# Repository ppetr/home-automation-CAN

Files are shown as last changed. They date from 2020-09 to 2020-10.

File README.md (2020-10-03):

# Home automation communication network

_*Disclaimer:* This is not an officially supported Google product._

This project aims to create both SW and HW for an inexpensive home automation
communication network based on the
[CAN bus](https://en.wikipedia.org/wiki/CAN_bus) using common components and
infrastructure.

Eventually it will contain hardware plans
([KiCAD](https://en.wikipedia.org/wiki/KiCad)) and software to control
individual modules.

At the moment subdirectories contain work in progress, untested, and not
suitable for any use whatsoever.

## Design goals:

* Local with respect to network changes. That is, changing one part of the
  network should not require modification of the network as a whole.
* Easy to use. Adding or removing devices should be simple.
* Allow complex topologies, ideally multi-star.
* Use existing infrastructure - CAT 5 cables and RJ45 connectors.
* Universal - modules should be able to provide GPIO pins, as well as standard
  short-range communication buses such as I²C.
* Inexpensive.

See also
[Linearizing multi-star network for home automation](https://electronics.stackexchange.com/questions/512147/linearizing-multi-star-network-for-home-automation)
on StackExchange.

## Detailed design

### RJ45 connector for CAN

The project uses the standard [RJ45](https://en.wikipedia.org/wiki/RJ45)
connector and [CAT5](https://en.wikipedia.org/wiki/Category_5_cable) (or better
cables).

For power distribution it uses pins 4 and 5 for positive voltage and pins 7 and
8 for negative (ground) voltage. This is compatible with [Power over
Ethernet](https://en.wikipedia.org/wiki/Power_over_Ethernet). It should be
possible to use any _passive_ PoE injector up to 48V.

Pin pairs 1 & 2 and 3 & 6 are used for the CAN bus. The standard requires that
the CAN bus data connections form a serial bus. In order to support arbitrary
tree [topologies](https://en.wikipedia.org/wiki/Network_topology), each node in
the network provides a linar segment of a CAN bus. This linear segment goes
from pins 1 (_LEFT CAN+_) and 2 (_LEFT CAN-_) to pins 3 (_RIGHT CAN+_) and 6
(_RIGHT CAN-_). All these segments are then concatenated into a single serial
line.

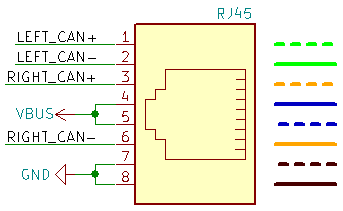
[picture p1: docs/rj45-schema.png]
RJ54 interface


A simple **end node** must connects pins 1-3 and 2-6 to connect the bus segment
"on its left" with the other segment "on its right". At the same time, it
connects its CAN transceiver to these pins and to the ground pins. It can also
draw power from the PoE positive voltage pins.

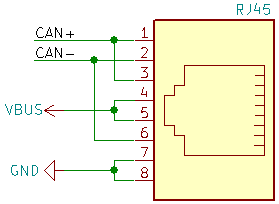
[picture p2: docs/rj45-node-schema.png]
RJ54 end node


A **splitter node** just connects the power pins among all RJ45 connectors. The
data pin connections are more complicated: The CAN network "going from the
left" is first connected to one branch (CAN1), the "right" part of the branch
is connected to the "left" part of the other branch (CAN2), and finally
continues "to the right" (CAN3).

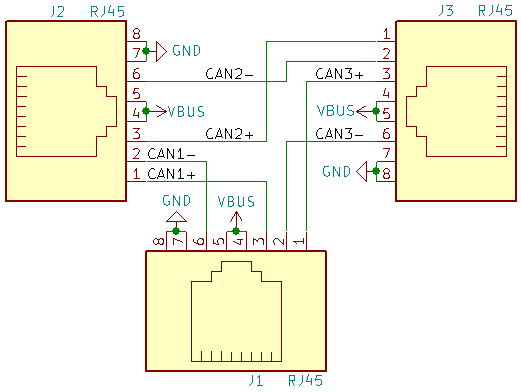
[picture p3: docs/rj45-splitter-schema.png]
RJ54 splitter node


This corresponds to depth-first
[tree traversal](https://en.wikipedia.org/wiki/Tree_traversal) of the network.

Notice that the splitter node is fully symmetric. Therefore any connector can
be used as the one connected to the main network, and all the others as
branches. It can also split into more than two branches. However, in any case
**all branches must be connected** to nodes, even just to dummy ones that only
connect pins 1-3 and 2-6, in order to ensure that the whole network is
interconnected.

Finally, exactly one node on the network must be a **terminating node**, to
provide proper
[electrical termination](https://en.wikipedia.org/wiki/Electrical_termination).
Without such a node the whole network would form a ring and suffer from echoes
(see also [Signal reflection](https://en.wikipedia.org/wiki/Signal_reflection)).

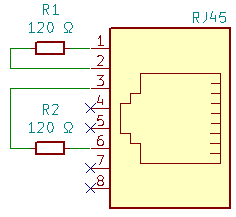
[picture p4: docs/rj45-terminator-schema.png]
RJ54 terminator node


## Contributions and future plans

Once a skeleton of the project becomes available, contributions will be
welcomed! Please see [Code of Conduct](docs/code-of-conduct.md) and
[Contributing](docs/contributing.md).

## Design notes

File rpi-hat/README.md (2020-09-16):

# Universal Raspberry Pi CAN Hat board

Provides CAN interface using the standard
[D-sub](https://en.wikipedia.org/wiki/D-subminiature) DE-9 connector and our
custom RJ-45 connector.

The board should comply to the requirements stated in
https://github.com/raspberrypi/hats. If you encounter any violation or
deviation, please open an issue.

The schema is loosely based on
https://www.disk91.com/2015/technology/hardware/design-a-raspberry-pi-hat-shield/

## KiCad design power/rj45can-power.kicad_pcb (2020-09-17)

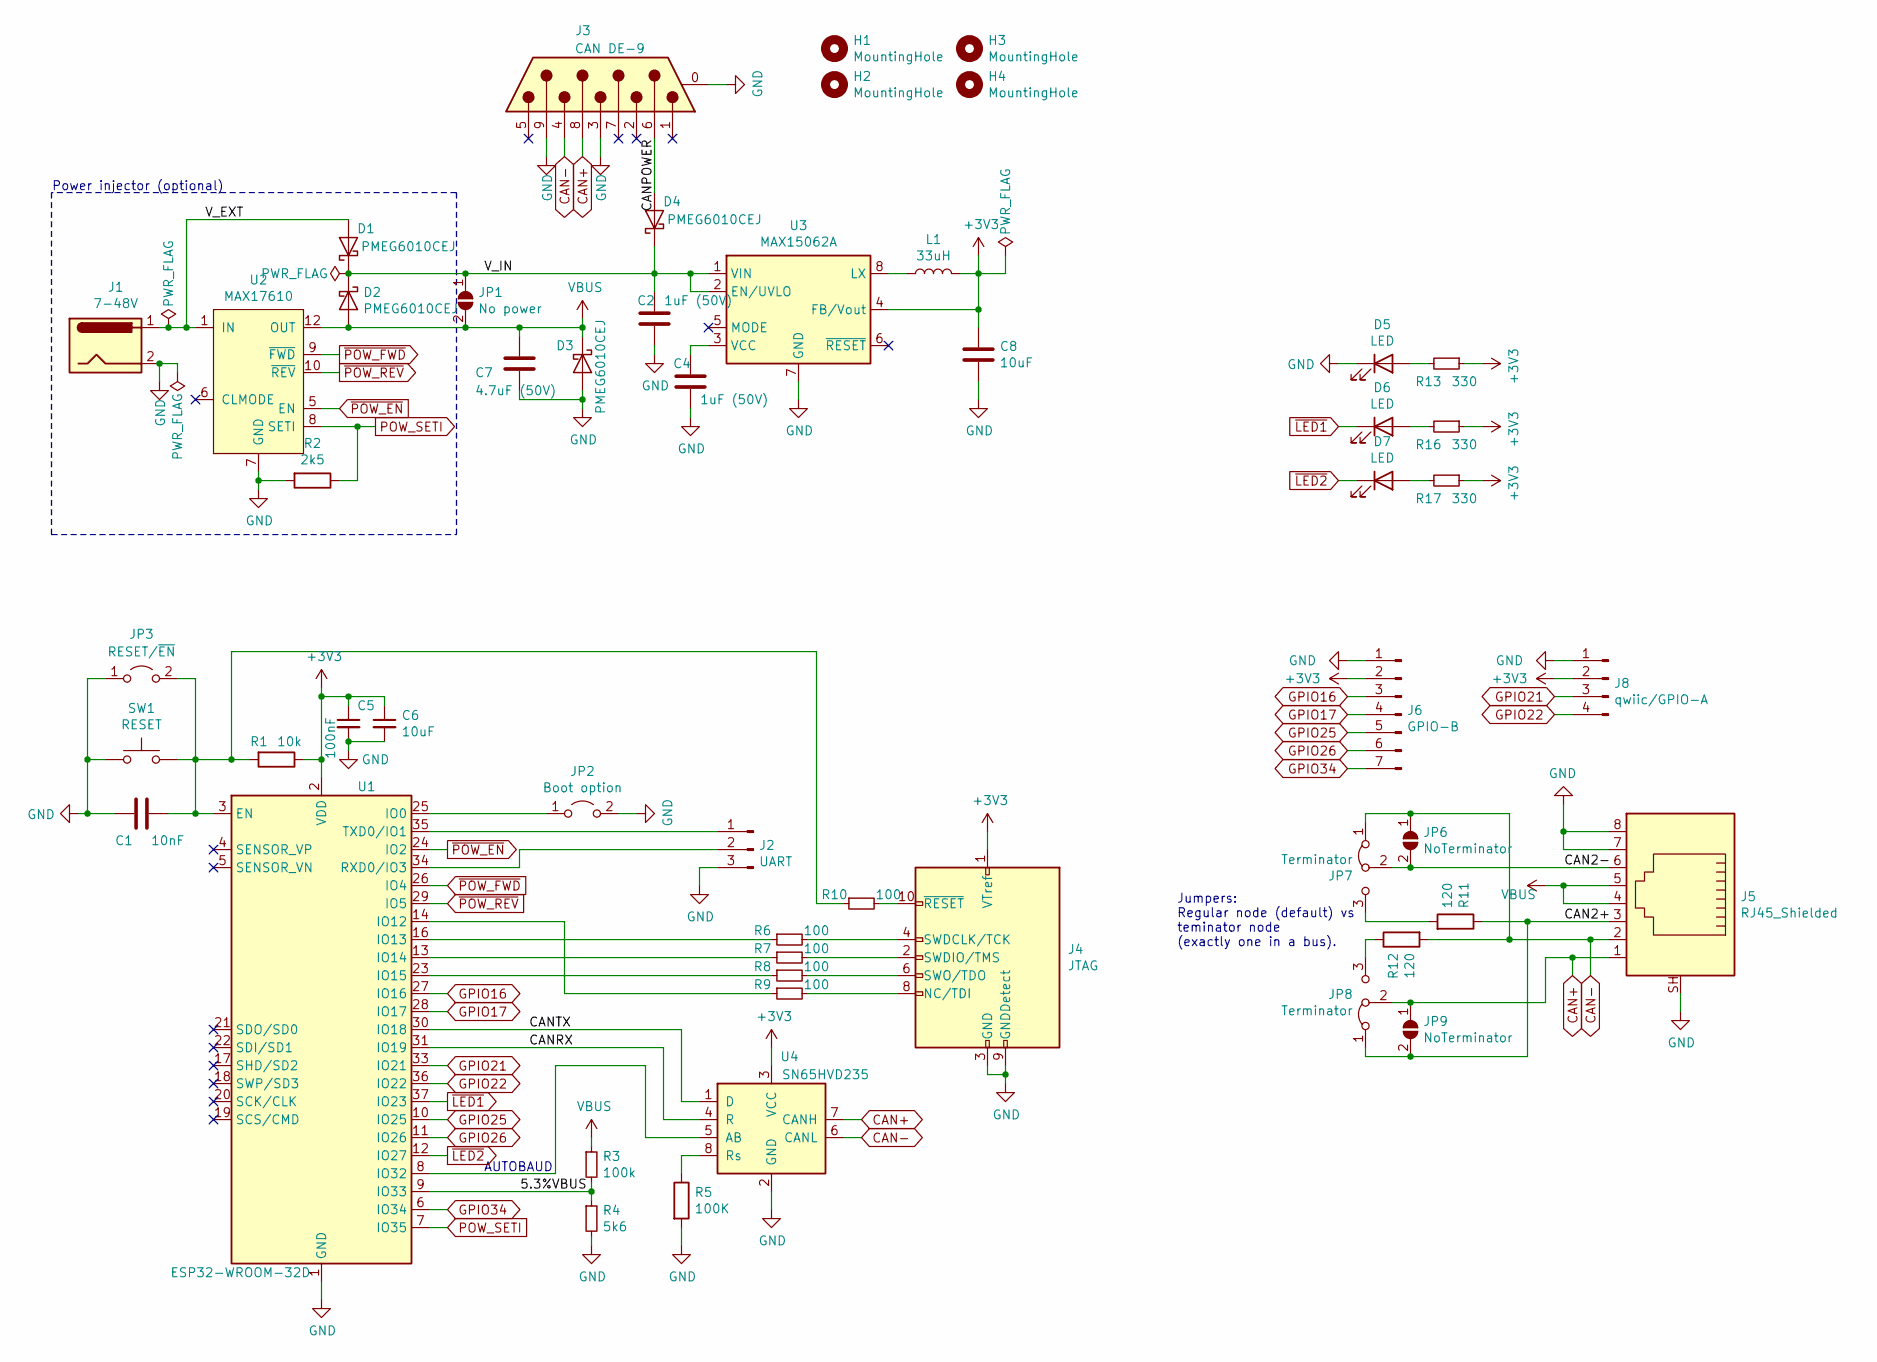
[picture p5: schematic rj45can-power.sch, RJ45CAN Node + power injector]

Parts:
C1: 10nF; C_0603_1608Metric_Pad1.05x0.95mm_HandSolder
C2, C4: 1uF (50V); C_0603_1608Metric_Pad1.05x0.95mm_HandSolder
C5: 100nF; C_0603_1608Metric_Pad1.05x0.95mm_HandSolder
C6, C8: 10uF; C_0603_1608Metric_Pad1.05x0.95mm_HandSolder
C7: 4.7uF (50V); C_0603_1608Metric_Pad1.05x0.95mm_HandSolder
D1, D2, D3, D4: PMEG6010CEJ; D_SOD-323F
D5, D6, D7: LED; LED_0603_1608Metric_Pad1.05x0.95mm_HandSolder
H1, H2, H3, H4: MountingHole; MountingHole_2.2mm_M2
J1: 7-48V; BarrelJack_Horizontal
J2: UART; JST_SH_BM03B-SRSS-TB_1x03-1MP_P1.00mm_Vertical
J3: CAN DE-9; DSUB-9_Male_Horizontal_P2.77x2.84mm_EdgePinOffset4.94mm_Hou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
J4: JTAG; IDC-Header_2x05_P2.54mm_Vertical
J5: RJ45_Shielded; RJ45_Ninigi_GE
J6: GPIO-B; JST_SH_BM07B-SRSS-TB_1x07-1MP_P1.00mm_Vertical
J8: qwiic/GPIO-A; JST_SH_BM04B-SRSS-TB_1x04-1MP_P1.00mm_Vertical
JP1: No power; SolderJumper-2_P1.3mm_Open_TrianglePad1.0x1.5mm
JP2: Boot option; TestPoint_2Pads_Pitch2.54mm_Drill0.8mm
JP3: RESET/~EN; PinHeader_1x02_P2.54mm_Vertical
JP6, JP9: NoTerminator; SolderJumper-2_P1.3mm_Open_Pad1.0x1.5mm
JP7, JP8: Terminator; PinHeader_1x03_P2.54mm_Vertical
L1: 33uH; L_Coilcraft_LPS4018
R1: 10k; R_0603_1608Metric_Pad1.05x0.95mm_HandSolder
R2: 2k5; R_0603_1608Metric_Pad1.05x0.95mm_HandSolder
R3: 100k; R_0603_1608Metric_Pad1.05x0.95mm_HandSolder
R4: 5k6; R_0603_1608Metric_Pad1.05x0.95mm_HandSolder
R5: 100K; R_0603_1608Metric_Pad1.05x0.95mm_HandSolder
R6, R7, R8, R9, R10: 100; R_0603_1608Metric_Pad1.05x0.95mm_HandSolder
R11, R12: 120; R_0603_1608Metric_Pad1.05x0.95mm_HandSolder
R13, R16, R17: 330; R_0603_1608Metric_Pad1.05x0.95mm_HandSolder
SW1: RESET; SW_SPST_FSMSM
U1: ESP32-WROOM-32D; ESP32-WROOM-32
U2: MAX17610
U3: MAX15062A; DFN-8_2x2mm_P0.5mm
U4: SN65HVD235; SOIC-8_3.9x4.9mm_P1.27mm

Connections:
+3V3: C5.1, C6.1, C8.1, J4.1 (VTref), J6.2, J8.2, L1.2, R1.1, R13.1, R16.1, R17.1, U1.2 (VDD), U3.4 (FB/Vout), U4.3 (VCC)
/5.3%VBUS: R3.2, R4.1, U1.9 (IO33)
/CAN2+: J5.3, JP8.1 (A), JP9.2 (B), R11.1
/CAN2-: J5.6, JP6.2 (B), JP7.2 (C)
/CANPOWER: D4.2 (A), J3.6
/CANRX: U1.31 (IO19), U4.4 (R)
/CANTX: U1.30 (IO18), U4.1 (D)
/V_EXT: D1.2 (A), J1.1, U2.1 (IN)
/V_IN: C2.1, D1.1 (K), D2.1 (K), D4.1 (K), JP1.1 (A), U3.1 (VIN), U3.2 (EN/UVLO)
CAN+: J3.8, J5.1, JP8.2 (C), JP9.1 (A), U4.7 (CANH)
CAN-: J3.4, J5.2, JP6.1 (A), JP7.1 (A), R12.2, U4.6 (CANL)
GND: C1.2, C2.2, C4.2, C5.2, C6.2, C7.1, C8.2, D3.2 (A), D5.1 (K), J1.2, J2.3, J3.0 (PAD), J3.3, J3.9, J4.3 (GND), J4.5 (GND), J4.9 (GNDDetect), J5.7, J5.8, J5.SH, J6.1, J8.1, JP2.2 (B), JP3.1 (A), R2.2, R4.2, R5.2, SW1.1, U1.1 (GND), U1.15 (GND), U1.38 (GND), U1.39 (GND), U2.7 (GND), U3.7 (GND), U4.2 (GND)
GPIO16: J6.3, U1.27 (IO16)
GPIO17: J6.4, U1.28 (IO17)
GPIO21: J8.3, U1.33 (IO21)
GPIO22: J8.4, U1.36 (IO22)
GPIO25: J6.5, U1.10 (IO25)
GPIO26: J6.6, U1.11 (IO26)
GPIO34: J6.7, U1.6 (IO34)
unnamed: C1.1, JP3.2 (B), R1.2, R10.1, SW1.2, U1.3 (EN)
unnamed: C4.1, U3.3 (VCC)
unnamed: D5.2 (A), R13.2
unnamed: D6.2 (A), R16.2
unnamed: D7.2 (A), R17.2
unnamed: J2.1, U1.35 (TXD0/IO1)
unnamed: J2.2, U1.34 (RXD0/IO3)
unnamed: J4.2 (SWDIO/TMS), R7.2
unnamed: J4.4 (SWDCLK/TCK), R6.2
unnamed: J4.6 (SWO/TDO), R8.2
unnamed: J4.8 (NC/TDI), R9.2
unnamed: J4.10 (~RESET~), R10.2
unnamed: JP2.1 (A), U1.25 (IO0)
unnamed: JP7.3 (B), R11.2
unnamed: JP8.3 (B), R12.1
unnamed: L1.1, U3.8 (LX)
unnamed: R5.1, U4.8 (Rs)
unnamed: R6.1, U1.16 (IO13)
unnamed: R7.1, U1.13 (IO14)
unnamed: R8.1, U1.23 (IO15)
unnamed: R9.1, U1.14 (IO12)
unnamed: U1.8 (IO32), U4.5 (AB)
POW_SETI: R2.1, U1.7 (IO35), U2.8 (SETI)
VBUS: C7.2, D2.2 (A), D3.1 (K), J5.4, J5.5, JP1.2 (B), R3.1, U2.12 (OUT)
~LED1: D6.1 (K), U1.37 (IO23)
~LED2: D7.1 (K), U1.12 (IO27)
~POW_EN: U1.24 (IO2), U2.5 (EN)
~POW_FWD: U1.26 (IO4), U2.9 (~FWD)
~POW_REV: U1.29 (IO5), U2.10 (~REV)

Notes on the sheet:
Power injector (optional)
AUTOBAUD
Jumpers: Regular node (default) vs teminator node (exactly one in a bus).

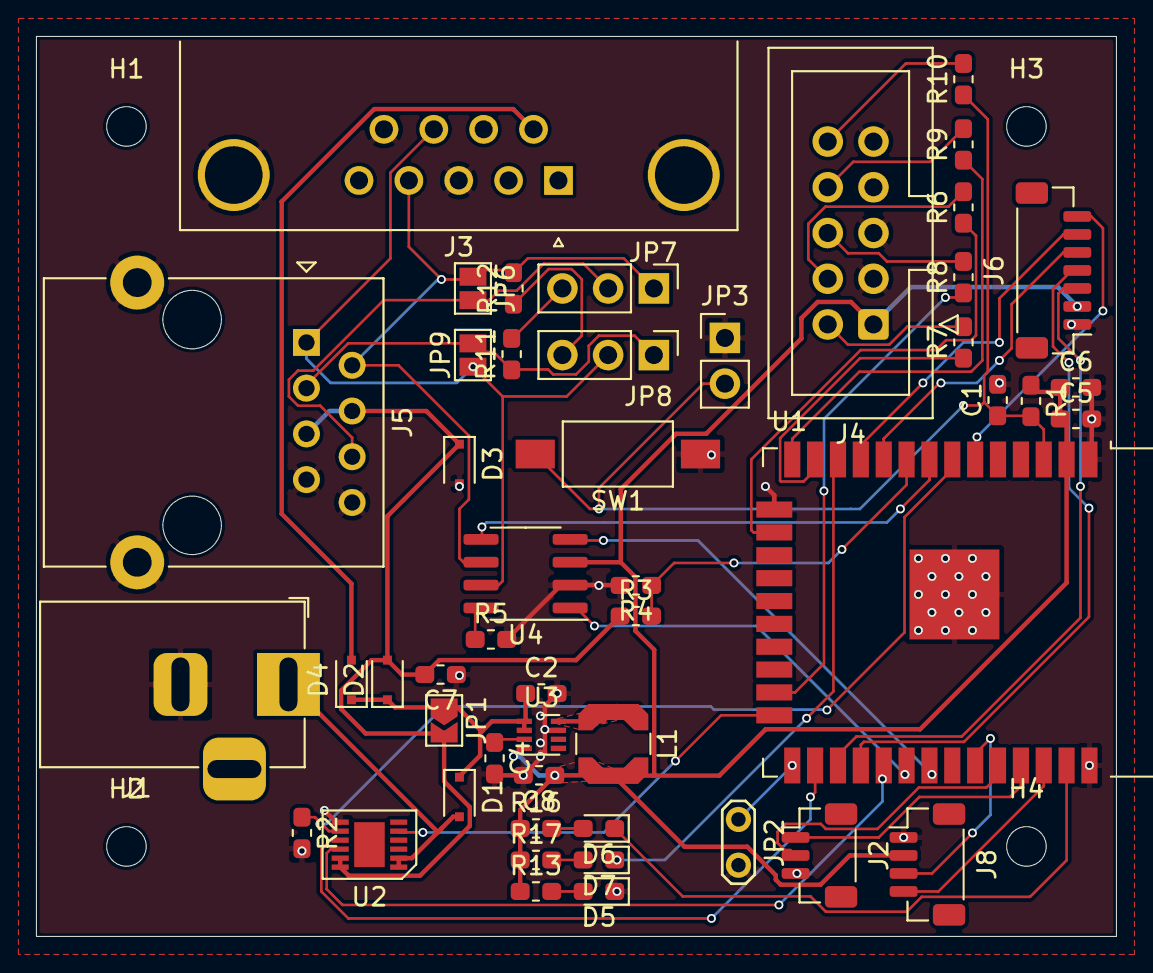
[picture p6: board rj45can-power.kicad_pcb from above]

Board: 2 copper layers, 60.0 x 50.0 mm, 53 parts (0 on the bottom side), 48 nets.

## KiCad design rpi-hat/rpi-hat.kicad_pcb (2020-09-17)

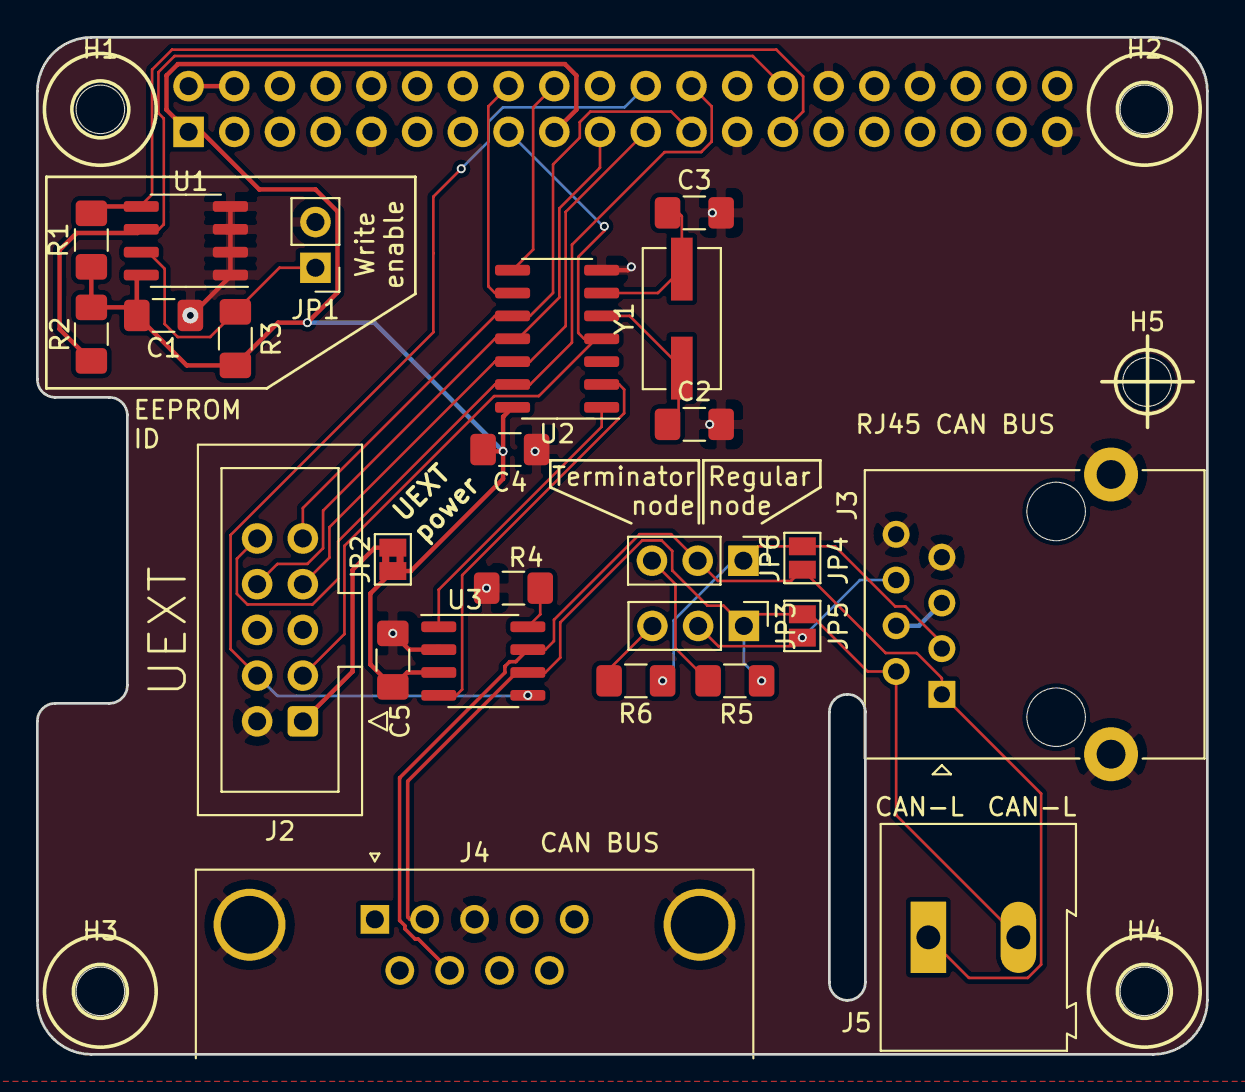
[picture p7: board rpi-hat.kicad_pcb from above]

Board: 2 copper layers, 65.0 x 56.5 mm, 31 parts (1 on the bottom side), 27 nets.

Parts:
C1, C4, C5: 100nF; C_1206_3216Metric_Pad1.42x1.75mm_HandSolder
C2, C3: 22pF; C_1206_3216Metric_Pad1.42x1.75mm_HandSolder
H1, H2, H3, H4, H5: Drill; MountingHole_2.7mm_M2.5_DIN965
J1: Raspberry_Pi_2_3; PinSocket_2x20_P2.54mm_Vertical
J2: UEXT_Slave; IDC-Header_2x05_P2.54mm_Vertical
J3: RJ45_Shielded; RJ45_Ninigi_GE
J4: DB9 Male CAN; DSUB-9_Male_Horizontal_P2.77x2.84mm_EdgePinOffset4.94mm_Hou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
J5: Screw_Terminal_01x02; TerminalBlock_Altech_AK300-2_P5.00mm
JP1: Write Enable; PinHeader_1x02_P2.54mm_Vertical
JP2: SolderJumper_2_Bridged; SolderJumper-2_P1.3mm_Bridged2Bar_Pad1.0x1.5mm
JP3, JP4: Terminator; PinHeader_1x03_P2.54mm_Vertical
JP5, JP6: NoTerminator; SolderJumper-2_P1.3mm_Open_Pad1.0x1.5mm
R1, R2: 3k9; R_1206_3216Metric_Pad1.42x1.75mm_HandSolder
R3: 1k; R_1206_3216Metric_Pad1.42x1.75mm_HandSolder
R4: 100k; R_1206_3216Metric_Pad1.42x1.75mm_HandSolder
R5, R6: 120; R_1206_3216Metric_Pad1.42x1.75mm_HandSolder
U1: CAT24C128; SOIC-8_3.9x4.9mm_P1.27mm
U2: MCP2517FD-xSL; SOIC-14_3.9x8.7mm_P1.27mm
U3: SN65HVD235; SOIC-8_3.9x4.9mm_P1.27mm
Y1: 20MHz; Crystal_SMD_ECS_CSM3X-2Pin_7.6x4.1mm

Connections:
+3V3: C1.1, C4.2, C5.2, J1.1, J1.17, JP2.1, R1.1, R2.1, R3.1, U1.8, U2.14, U3.3
+5V: J1.2, J1.4
/CAN2+: J3.3, JP4.1, JP6.2, R6.1
/CAN2-: J3.6, JP3.2, JP5.2
/MISO: J1.21, J2.7, U2.12
/MOSI: J1.19, J2.8, U2.11
/RXCAN: U2.2, U3.4
/SCK: J1.23, J2.9, U2.10
/TXCAN: U2.1, U3.1
/UEXT_POWER: J2.1, JP2.2
/VBUS: J3.4, J3.5
/WRITE_PROTECT: JP1.1, R3.2, U1.7
/~SSEL: J1.24, J2.10, U2.13
AUTOBAUD: J1.22, J2.4, U3.5
CAN+: J3.1, J4.7, J5.1, JP4.2, JP6.1, U3.7
CAN-: J3.2, J4.2, J5.2, JP3.1, JP5.1, R5.2, U3.6
GND: C1.2, C2.2, C3.2, C4.1, C5.1, J1.6, J1.9, J1.14, J1.20, J1.25, J1.30, J1.34, J1.39, J2.2, J3.7, J3.8, J3.SH, J4.0, J4.3, JP1.2, R4.2, U1.1, U1.2, U1.3, U1.4, U2.7, U3.2
ID_SC: J1.28, R2.2, U1.6
ID_SD: J1.27, R1.2, U1.5
unnamed: C2.1, U2.5, Y1.1
unnamed: C3.1, U2.6, Y1.2
unnamed: JP3.3, R6.2
unnamed: JP4.3, R5.1
unnamed: R4.1, U3.8
~INT: J1.15, J2.3, U2.4
~INT0: J1.16, U2.9
~INT1: J1.18, U2.8

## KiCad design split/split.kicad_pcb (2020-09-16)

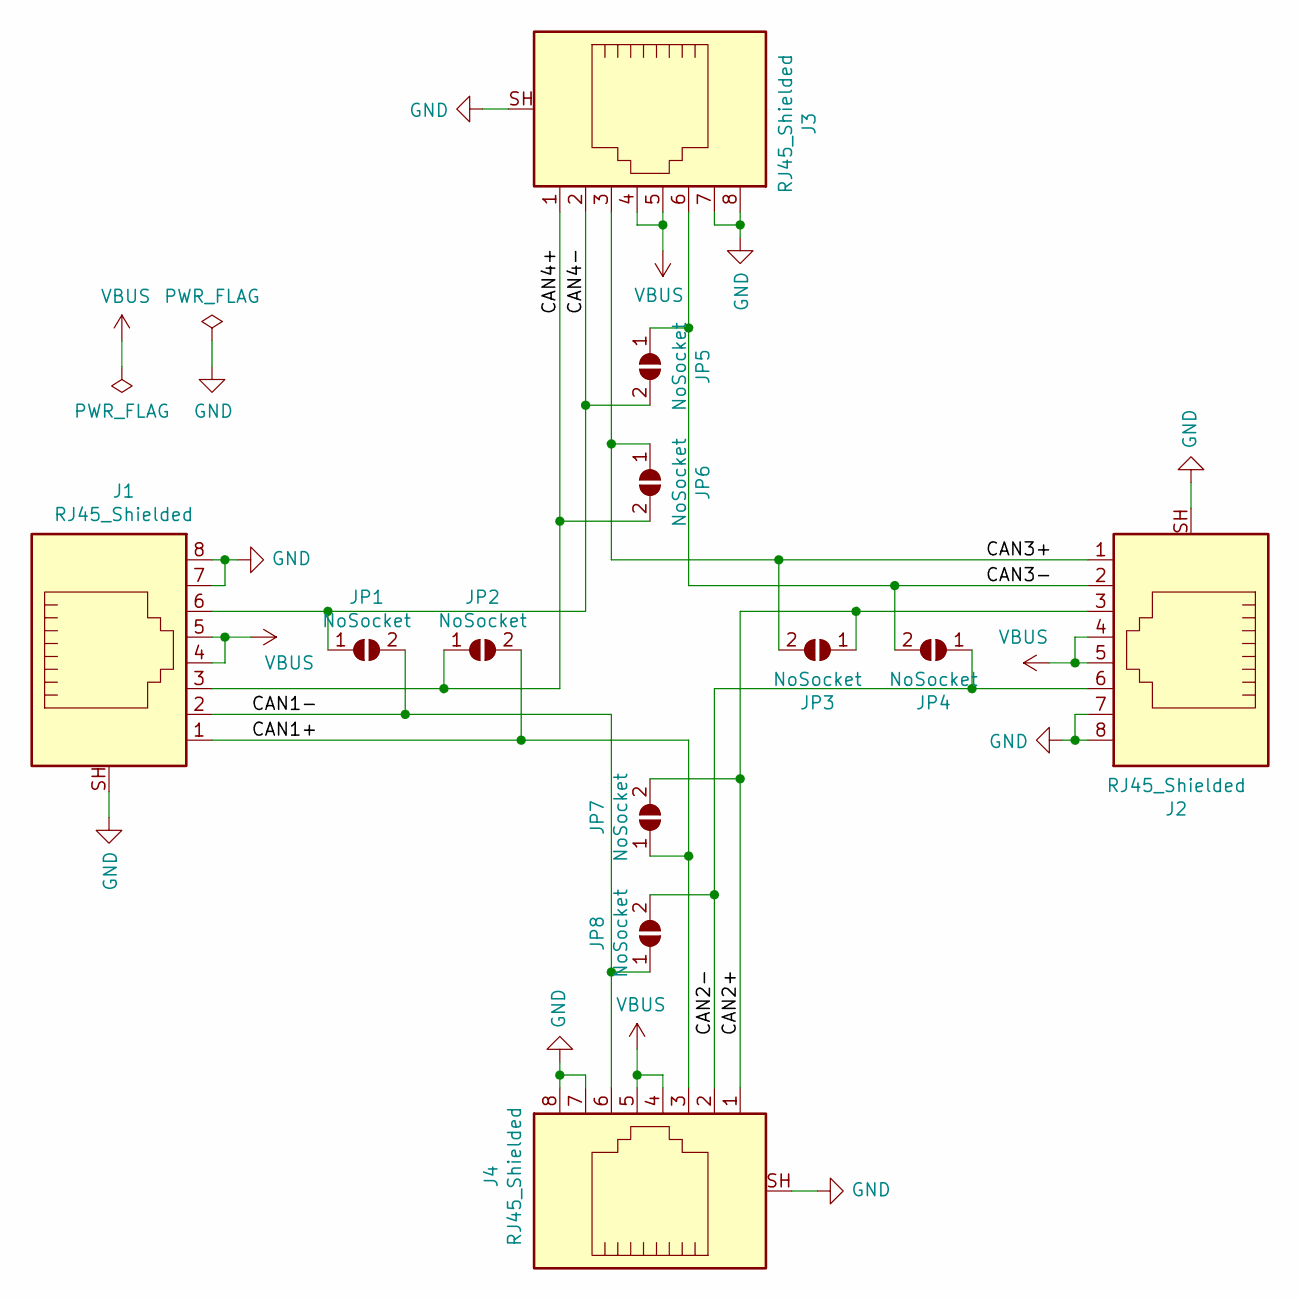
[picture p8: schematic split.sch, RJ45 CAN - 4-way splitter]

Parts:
J1, J2, J3, J4: RJ45_Shielded; RJ45_Ninigi_GE
JP1, JP2, JP3, JP4, JP5, JP6, JP7, JP8: NoSocket; SolderJumper-2_P1.3mm_Open_RoundedPad1.0x1.5mm

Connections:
/CAN1+: J1.1, J4.3, JP2.2 (B), JP7.1 (A)
/CAN1-: J1.2, J4.6, JP1.2 (B), JP8.1 (A)
/CAN2+: J2.3, J4.1, JP3.1 (A), JP7.2 (B)
/CAN2-: J2.6, J4.2, JP4.1 (A), JP8.2 (B)
/CAN3+: J2.1, J3.3, JP3.2 (B), JP6.1 (A)
/CAN3-: J2.2, J3.6, JP4.2 (B), JP5.1 (A)
/CAN4+: J1.3, J3.1, JP2.1 (A), JP6.2 (B)
/CAN4-: J1.6, J3.2, JP1.1 (A), JP5.2 (B)
GND: J1.7, J1.8, J1.SH, J2.7, J2.8, J2.SH, J3.7, J3.8, J3.SH, J4.7, J4.8, J4.SH
VBUS: J1.4, J1.5, J2.4, J2.5, J3.4, J3.5, J4.4, J4.5

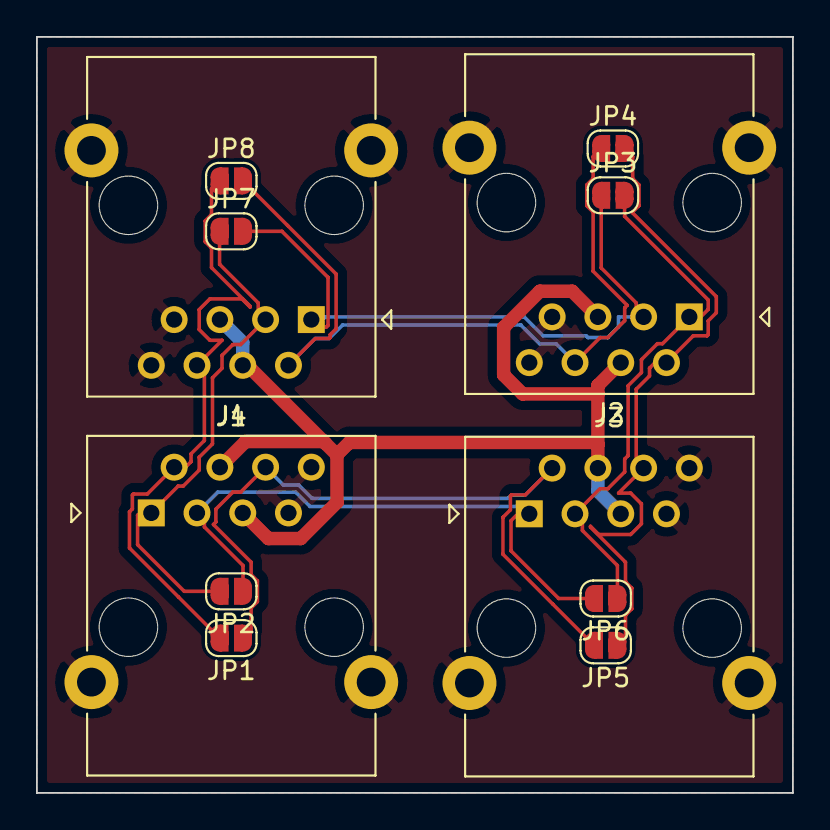
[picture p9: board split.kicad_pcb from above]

Board: 2 copper layers, 42.0 x 42.0 mm, 12 parts (0 on the bottom side), 10 nets.

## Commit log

2020-09-16 Initial import of KiCAD schema and PCB layout files
    [rj45can-power.kicad_pcb, rj45can-power.sch, rj45can.sch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]
2020-09-17 Fix problems with project-specific library
    Use 1206/3216Metric footprints for all capacitors and resistors.
    Fix QR code to be negative and to point to the proper address.
    [rj45can-power.kicad_pcb, rpi-hat.kicad_pcb, rpi-hat.sch]
2020-10-03 Document our connection of the CAN bus through RJ45 connectors

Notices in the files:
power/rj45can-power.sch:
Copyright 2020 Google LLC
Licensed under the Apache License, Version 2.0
